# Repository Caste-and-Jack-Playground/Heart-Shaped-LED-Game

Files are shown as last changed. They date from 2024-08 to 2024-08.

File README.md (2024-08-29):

# Heart-Shaped-LED-Game
This cute game will test your reflexes and rythm.\
It's pretty easy to use, there are just two buttons for two players.
The goal is to press the button when the leds on the top are at their maximum or minimum brightness.\
When you win, the leds on your side will blink.\
Then you'll get to the next level where the leds will fade on and off even faster.\
This game can be played alone, with a friend or maybe even a lover.

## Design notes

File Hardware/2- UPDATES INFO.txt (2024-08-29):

v1.0:
It doesn't even work out of the box lol

v1.1:
- Button traces corrected. Now they do work out of the box 
- Newer buttons with increased operating force, cheaper and more common
- Hole added for optional keychain

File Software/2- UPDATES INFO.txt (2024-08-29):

v1.0:
- There are two red leds that keep fading slowly from 100% to 0%
- There are two groups of 4 leds around the two buttons but they're fixed.
- The point of the game is to test the reflexes between two players or by yourself.
  To win, you have to press the button when the red led are at 100% or 0% brightness.
  When someone of the two win, the loser player side shuts off and the one who won,
  starts blinking for a few secs.
  After this, the game starts again but with the red leds fading even faster.
  The two players have to try again with the game being even faster.
  This game have no end.

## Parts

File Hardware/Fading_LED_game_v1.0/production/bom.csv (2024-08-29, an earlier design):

Designator | Footprint | Quantity | Value | LCSC Part #
BT1 | CR2032_BAT-HLD-001 | 1 | CR2032_BAT-HLD-001
C1, C3, C5, C6, C7 | 0402 | 5 | 100nF 50V
C2, C4 | 0603 | 2 | 10uF 10V
D1, D2, D3, D4 | 0603 | 4 | LED_P1
D10, D9 | 0805 | 2 | LED
D5, D6, D7, D8 | 0603 | 4 | LED_P2
LPC802 | mcu LPC802 | 1 | mcu LPC802M001JDH16J
PLAYER_1, PLAYER_2 | Button_EVP-BT2G4A000 | 2 | Button_EVP-BT2G4A000
Q1, Q2, Q3, Q4 | SOT-23 | 4 | BC817
R1, R2, R3 | 0402 | 3 | 10k
R10, R11, R12, R13, R6, R7, R8, R9 | 0603 | 8 | 10k
R14, R15, R16, R17 | 0603 | 4 | 750
R4, R5 | 0402 | 2 | 47k
S1 | Switch_CUS-12TB | 1 | Switch_CUS-12TB

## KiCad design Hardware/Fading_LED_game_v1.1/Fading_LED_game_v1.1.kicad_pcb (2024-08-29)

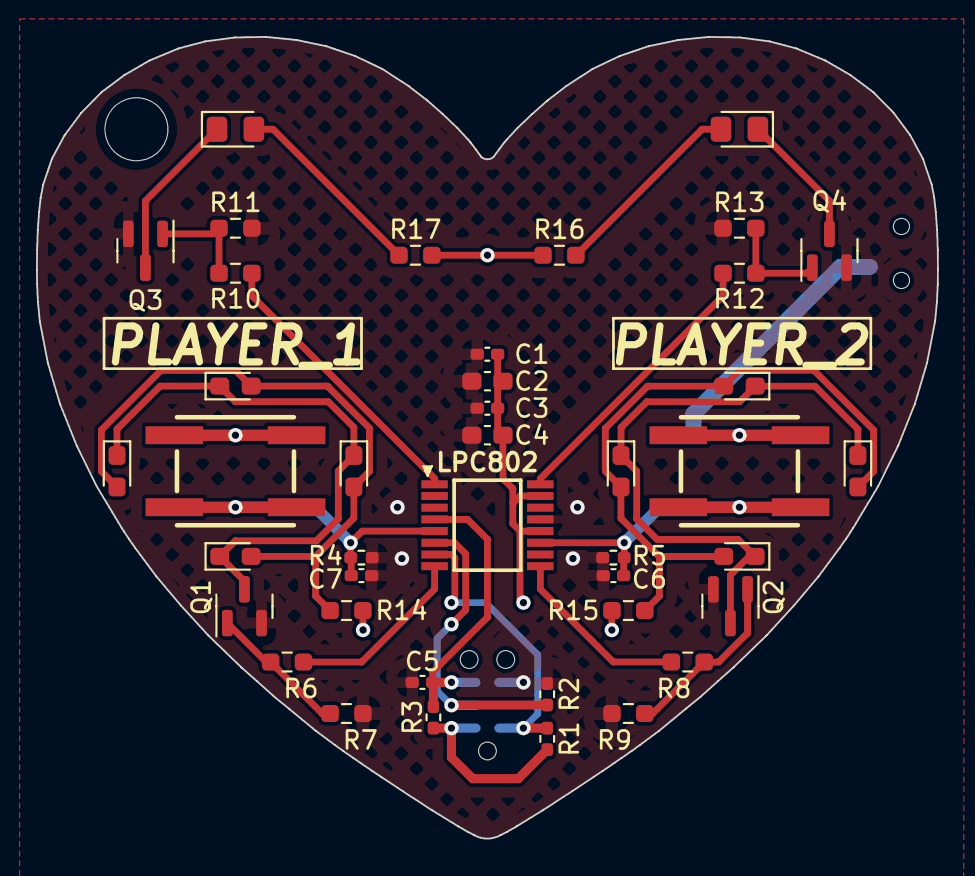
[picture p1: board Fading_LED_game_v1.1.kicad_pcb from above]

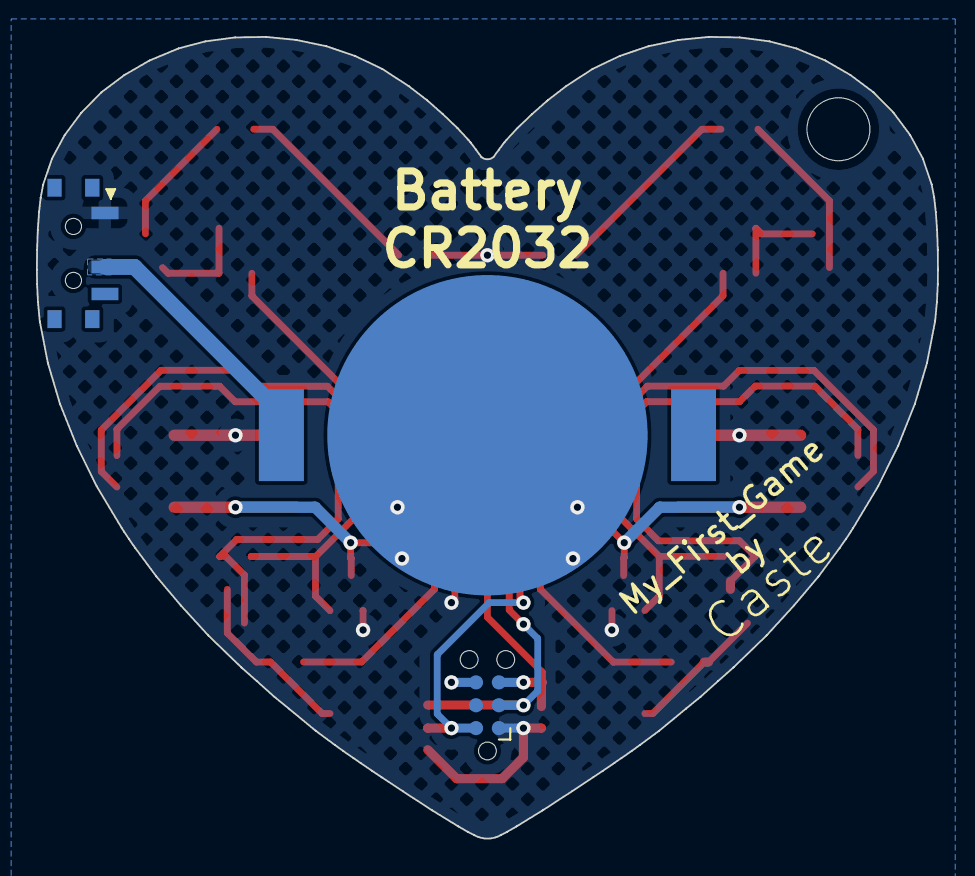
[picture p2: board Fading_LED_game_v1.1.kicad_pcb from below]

Board: 2 copper layers, 50.1 x 44.5 mm, 44 parts (3 on the bottom side), 24 nets.

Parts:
BT1: CR2032_BAT-HLD-001
C1, C3, C5, C6, C7: 100nF 50V; C_0402_1005Metric_Pad0.74x0.62mm_HandSolder
C2, C4: 10uF 10V; C_0603_1608Metric_Pad1.08x0.95mm_HandSolder
D1: PINK_LED_P1; LED_0603_1608Metric_Pad1.05x0.95mm_HandSolder
D2, D3, D4: LED_P1; LED_0603_1608Metric_Pad1.05x0.95mm_HandSolder
D5, D6, D7, D8: LED_P2; LED_0603_1608Metric_Pad1.05x0.95mm_HandSolder
D9, D10: LED; LED_0805_2012Metric_Pad1.15x1.40mm_HandSolder
J1: Prog conn; Tag-Connect_TC2030-IDC-NL_2x03_P1.27mm_Vertical
LPC802: mcu LPC802M001JDH16J; mcu LPC802
PLAYER_1, PLAYER_2: Button EVQ-Q2K03W; Button EVQ-Q2B03W
Q1, Q2, Q3, Q4: BC817; SOT-23
R1, R2, R3: 10k; R_0402_1005Metric_Pad0.72x0.64mm_HandSolder
R4, R5: 47k; R_0402_1005Metric_Pad0.72x0.64mm_HandSolder
R6, R7, R8, R9, R10, R11, R12, R13: 10k; R_0603_1608Metric_Pad0.98x0.95mm_HandSolder
R14, R15, R16, R17: 750; R_0603_1608Metric_Pad0.98x0.95mm_HandSolder
S1: Switch_CUS-12TB

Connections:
+3V3: C1.2, C2.2, C3.2, C4.2, J1.1 (VCC), LPC802.12 (VDD), LPC802.15 (VREFP), PLAYER_1.1 (A), PLAYER_1.4 (A'), PLAYER_2.1 (A), PLAYER_2.4 (A'), R1.1, R3.1, R14.2, R15.2, R16.2, R17.2, S1.1 (NO)
+BATT: BT1.1 (+_1), S1.2 (COM)
/!RST: C5.2, J1.5 (GND), LPC802.4 (~RESET/PIO0_5), R3.2
/+: C7.2, LPC802.5 (PIO0_4/ADC_11/NTRST), PLAYER_1.2 (B), PLAYER_1.3 (B'), R4.1
/-: C6.2, LPC802.11 (PIO0_8/ADC_5), PLAYER_2.2 (B), PLAYER_2.3 (B'), R5.1
/LEDS_BL: LPC802.8 (PIO0_11/ADC_6/WKTCLKIN), R6.1
/LEDS_BR: LPC802.9 (PIO0_1/ADC_0/ACMP_I2/CLKIN/TDI), R8.1
/LEDS_L: LPC802.1 (PIO0_17/ADC_9), R10.1
/LEDS_R: LPC802.16 (PIO0_0/ACMP_I1/TDO), R12.1
/SWCLK: J1.3 (~RESET), LPC802.6 (PIO0_3/SWCLK/TCK), R2.1
/SWDIO: J1.2 (SWDIO), LPC802.7 (PIO0_2/SWDIO/TMS), R1.2
GND: BT1.3 (-), C1.1, C2.1, C3.1, C4.1, C5.1, C6.1, C7.1, J1.6 (SWO), LPC802.13 (VSS), Q1.2 (E), Q2.2 (E), Q3.2 (E), Q4.2 (E), R2.2, R4.2, R5.2, R7.2, R9.2, R11.2, R13.2
unnamed: D1.2 (A), D2.2 (A), D3.2 (A), D4.2 (A), R14.1
unnamed: D1.1 (K), D2.1 (K), D3.1 (K), D4.1 (K), Q1.3 (C)
unnamed: D5.2 (A), D6.2 (A), D7.2 (A), D8.2 (A), R15.1
unnamed: D5.1 (K), D6.1 (K), D7.1 (K), D8.1 (K), Q2.3 (C)
unnamed: D9.2 (A), R17.1
unnamed: D9.1 (K), Q3.3 (C)
unnamed: D10.2 (A), R16.1
unnamed: D10.1 (K), Q4.3 (C)
unnamed: Q1.1 (B), R6.2, R7.1
unnamed: Q2.1 (B), R8.2, R9.1
unnamed: Q3.1 (B), R10.2, R11.1
unnamed: Q4.1 (B), R12.2, R13.1

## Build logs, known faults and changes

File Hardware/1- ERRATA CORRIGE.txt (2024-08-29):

v1.0:
- Sometimes, without any reason, the game restart.
  I suppose that's caused by accidentally touching the jtag connection on the back with bare hands.
- Buttons pad are wrongly connected. They are always shorted 
- Buttons are too weak and prone to failure

v1.1:
- Sometimes, without any reason, the game restart.
  I suppose that's caused by accidentally touching the jtag connection on the back with bare hands.
